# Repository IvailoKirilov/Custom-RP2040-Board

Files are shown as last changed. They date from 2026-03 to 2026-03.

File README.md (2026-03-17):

# Custom-RP2040-Board
This board is a simple RP2040 based MCU. The PCB was made with the help of the guide from Hack Club Stasis. 

I decided to make this board because I had wanted to make my own MCU for a while and when I saw the guide I instantly knew I had to make it. I learned quite a bit while making this project and now I will be bale to use this board for other projects.

This board has taken me about 7-8 hours to fully make. Below I have put some images of the finished board.

Schematic:

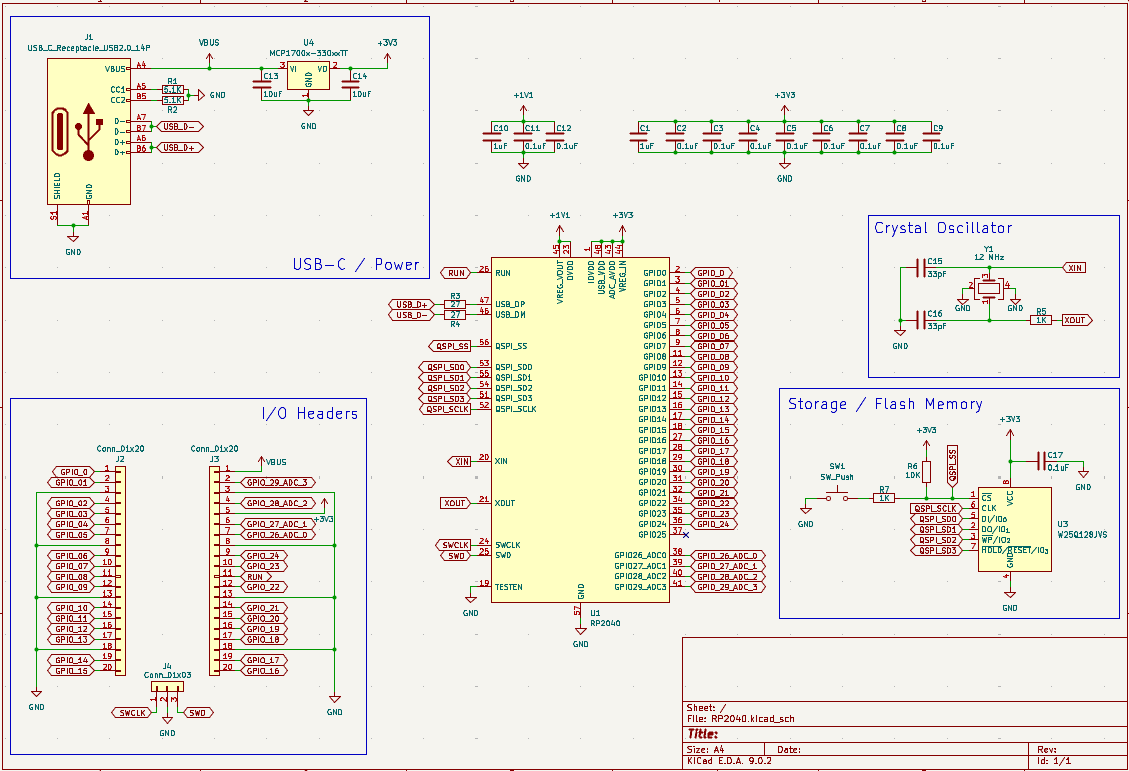
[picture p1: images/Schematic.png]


PCB (front):

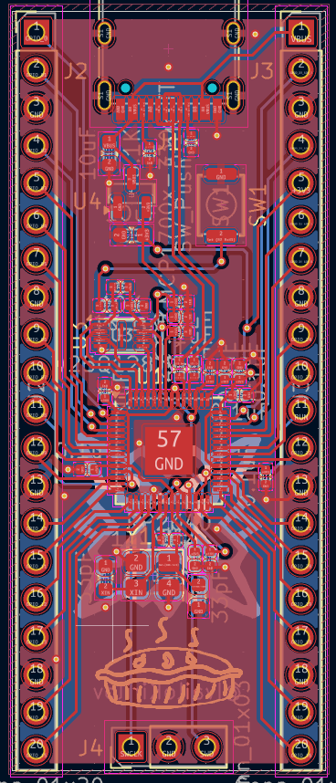
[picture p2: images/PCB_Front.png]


PCB (back):

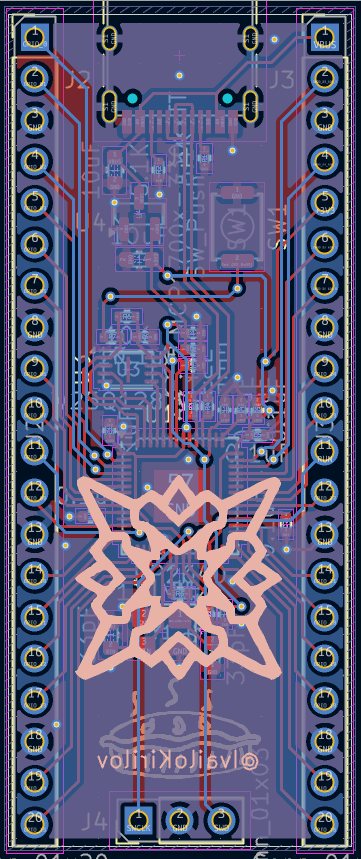
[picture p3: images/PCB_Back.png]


3D View (top):

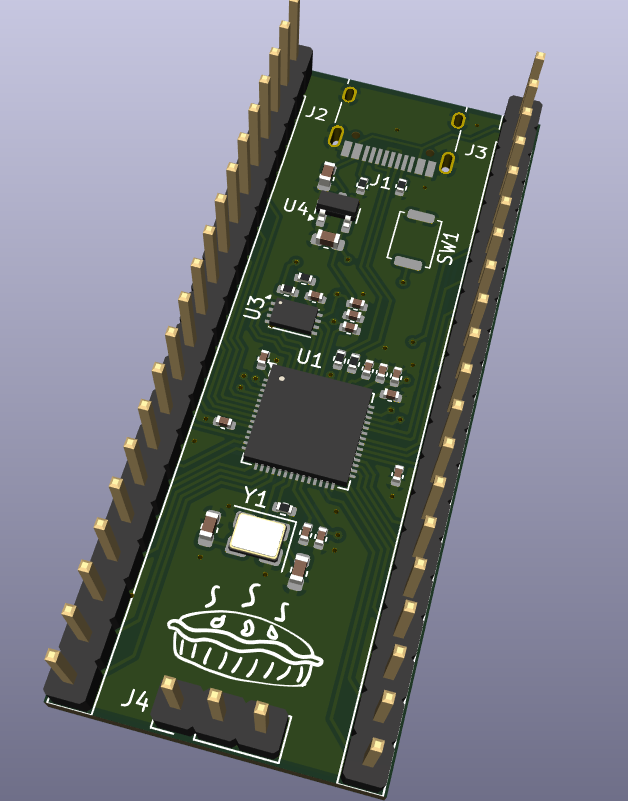
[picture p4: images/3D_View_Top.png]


3D View (bottom):

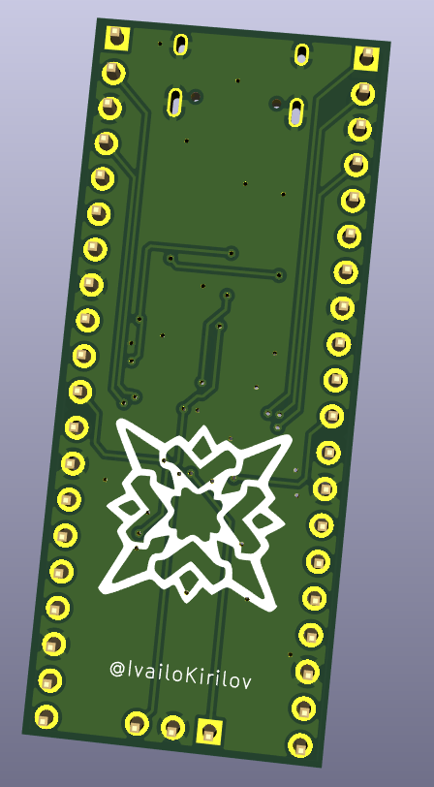
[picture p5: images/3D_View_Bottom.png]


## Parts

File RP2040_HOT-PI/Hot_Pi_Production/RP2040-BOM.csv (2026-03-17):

Id | Designator | Footprint | Quantity | Comment | Supplier and ref
1 | R5,R7 | R_0402_1005Metric | 2 | 1K
2 | SW1 | SW_Push_SPST_NO_Alps_SKRK | 1 | SW_Push
3 | C17,C9,C3,C2,C7,C6,C8,C11,C12,C4,C5 | C_0402_1005Metric | 11 | 0.1uF
4 | R3,R4 | R_0402_1005Metric | 2 | 27
5 | R6 | R_0402_1005Metric | 1 | 10K
6 | C16,C15 | C_0603_1608Metric | 2 | 33pF
7 | U3 | Winbond_USON-8-1EP_3x2mm_P0.5mm_EP0.2x1.6mm | 1 | W25Q128JVS
8 | C1,C10 | C_0402_1005Metric | 2 | 1uF
9 | R1,R2 | R_0402_1005Metric | 2 | 5.1K
10 | J2,J3 | PinHeader_1x20_P2.54mm_Vertical | 2 | Conn_01x20
11 | C13,C14 | C_0603_1608Metric | 2 | 10uF
12 | J4 | PinHeader_1x03_P2.54mm_Vertical | 1 | Conn_01x03
13 | Y1 | Crystal_SMD_3225-4Pin_3.2x2.5mm | 1 | 12 MHz
14 | U1 | QFN-56-1EP_7x7mm_P0.4mm_EP3.2x3.2mm | 1 | RP2040
15 | U4 | SOT-23 | 1 | MCP1700x-330xxTT
16 | J1 | USB_C_Receptacle_HRO_TYPE-C-31-M-12 | 1 | USB_C_Receptacle_USB2.0_14P

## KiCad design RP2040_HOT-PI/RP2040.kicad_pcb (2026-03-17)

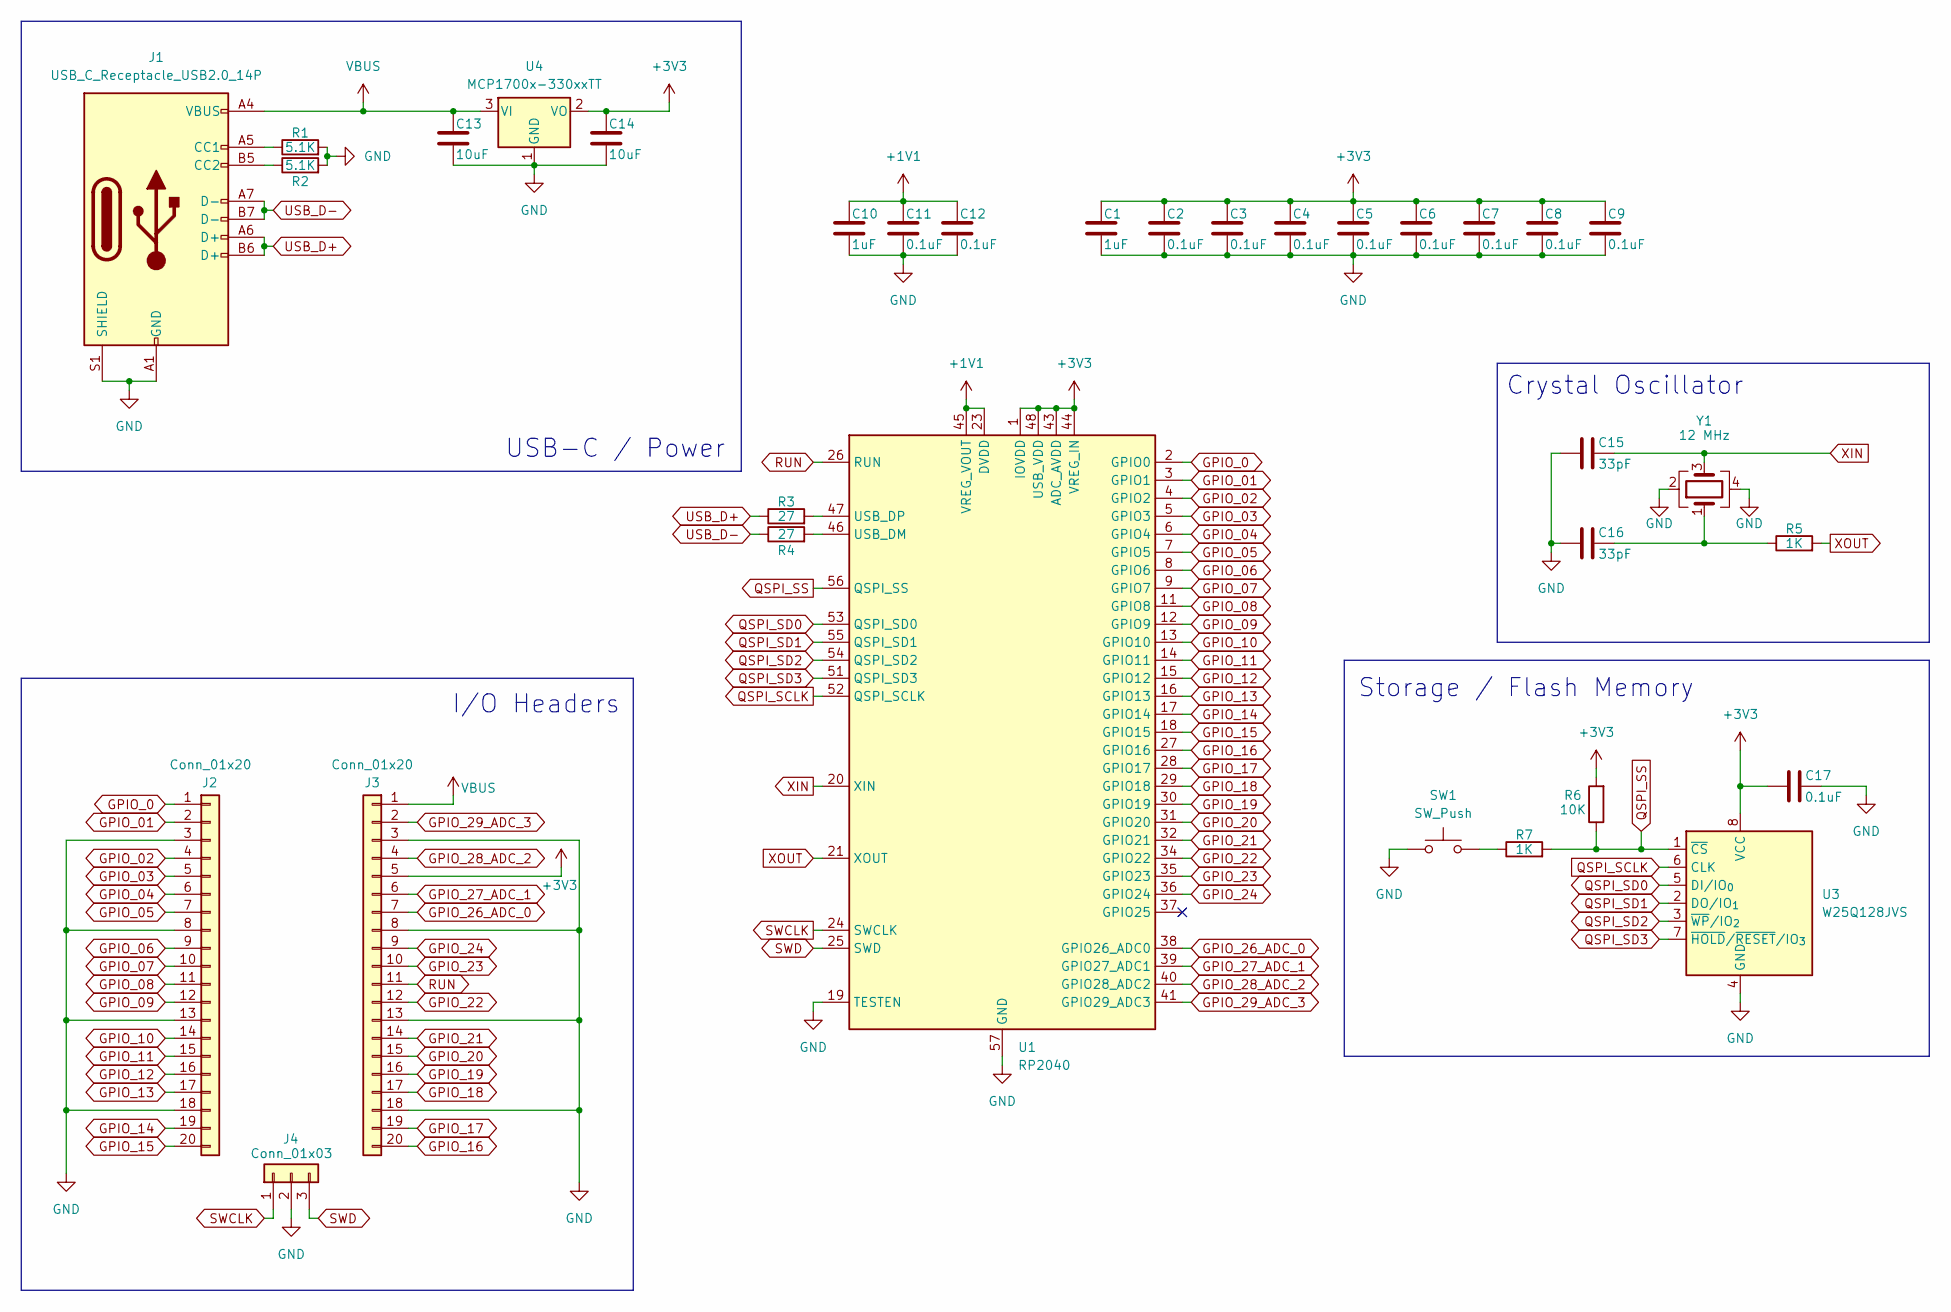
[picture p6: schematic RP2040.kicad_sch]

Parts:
C1, C10: 1uF; C_0402_1005Metric
C2, C3, C4, C5, C6, C7, C8, C9, C11, C12, C17: 0.1uF; C_0402_1005Metric
C13, C14: 10uF; C_0603_1608Metric
C15, C16: 33pF; C_0603_1608Metric
J1: USB_C_Receptacle_USB2.0_14P; USB_C_Receptacle_HRO_TYPE-C-31-M-12
J2, J3: Conn_01x20; PinHeader_1x20_P2.54mm_Vertical
J4: Conn_01x03; PinHeader_1x03_P2.54mm_Vertical
R1, R2: 5.1K; R_0402_1005Metric
R3, R4: 27; R_0402_1005Metric
R5, R7: 1K; R_0402_1005Metric
R6: 10K; R_0402_1005Metric
SW1: SW_Push; SW_Push_SPST_NO_Alps_SKRK
U1: RP2040; QFN-56-1EP_7x7mm_P0.4mm_EP3.2x3.2mm
U3: W25Q128JVS; Winbond_USON-8-1EP_3x2mm_P0.5mm_EP0.2x1.6mm
U4: MCP1700x-330xxTT; SOT-23
Y1: 12 MHz; Crystal_SMD_3225-4Pin_3.2x2.5mm

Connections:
+1V1: C10.1, C11.1, C12.1, U1.23 (DVDD), U1.45 (VREG_VOUT), U1.50 (DVDD)
+3V3: C1.1, C2.1, C3.1, C4.1, C5.1, C6.1, C7.1, C8.1, C9.1, C14.1, C17.1, J3.5, R6.2, U1.1 (IOVDD), U1.10 (IOVDD), U1.22 (IOVDD), U1.33 (IOVDD), U1.42 (IOVDD), U1.43 (ADC_AVDD), U1.44 (VREG_IN), U1.48 (USB_VDD), U1.49 (IOVDD), U3.8 (VCC), U4.2 (VO)
GND: C1.2, C2.2, C3.2, C4.2, C5.2, C6.2, C7.2, C8.2, C9.2, C10.2, C11.2, C12.2, C13.2, C14.2, C15.1, C16.1, C17.2, J1.A1 (GND), J1.A12 (GND), J1.B1 (GND), J1.B12 (GND), J1.S1 (SHIELD), J2.3, J2.8, J2.13, J2.18, J3.3, J3.8, J3.13, J3.18, J4.2, R1.2, R2.2, SW1.1, U1.19 (TESTEN), U1.57 (GND), U3.4 (GND), U4.1 (GND), Y1.2, Y1.4
GPIO_0: J2.1, U1.2 (GPIO0)
GPIO_01: J2.2, U1.3 (GPIO1)
GPIO_02: J2.4, U1.4 (GPIO2)
GPIO_03: J2.5, U1.5 (GPIO3)
GPIO_04: J2.6, U1.6 (GPIO4)
GPIO_05: J2.7, U1.7 (GPIO5)
GPIO_06: J2.9, U1.8 (GPIO6)
GPIO_07: J2.10, U1.9 (GPIO7)
GPIO_08: J2.11, U1.11 (GPIO8)
GPIO_09: J2.12, U1.12 (GPIO9)
GPIO_10: J2.14, U1.13 (GPIO10)
GPIO_11: J2.15, U1.14 (GPIO11)
GPIO_12: J2.16, U1.15 (GPIO12)
GPIO_13: J2.17, U1.16 (GPIO13)
GPIO_14: J2.19, U1.17 (GPIO14)
GPIO_15: J2.20, U1.18 (GPIO15)
GPIO_16: J3.20, U1.27 (GPIO16)
GPIO_17: J3.19, U1.28 (GPIO17)
GPIO_18: J3.17, U1.29 (GPIO18)
GPIO_19: J3.16, U1.30 (GPIO19)
GPIO_20: J3.15, U1.31 (GPIO20)
GPIO_21: J3.14, U1.32 (GPIO21)
GPIO_22: J3.12, U1.34 (GPIO22)
GPIO_23: J3.10, U1.35 (GPIO23)
GPIO_24: J3.9, U1.36 (GPIO24)
GPIO_26_ADC_0: J3.7, U1.38 (GPIO26_ADC0)
GPIO_27_ADC_1: J3.6, U1.39 (GPIO27_ADC1)
GPIO_28_ADC_2: J3.4, U1.40 (GPIO28_ADC2)
GPIO_29_ADC_3: J3.2, U1.41 (GPIO29_ADC3)
unnamed: C16.2, R5.1, Y1.1
unnamed: J1.A5 (CC1), R1.1
unnamed: J1.B5 (CC2), R2.1
unnamed: R7.1, SW1.2
unnamed: R4.2, U1.46 (USB_DM)
unnamed: R3.2, U1.47 (USB_DP)
QSPI_SCLK: U1.52 (QSPI_SCLK), U3.6 (CLK)
QSPI_SD0: U1.53 (QSPI_SD0), U3.5 (DI/IO_{0})
QSPI_SD1: U1.55 (QSPI_SD1), U3.2 (DO/IO_{1})
QSPI_SD2: U1.54 (QSPI_SD2), U3.3 (~WP/IO_{2})
QSPI_SD3: U1.51 (QSPI_SD3), U3.7 (~HOLD/~RESET/IO_{3})
QSPI_SS: R6.1, R7.2, U1.56 (QSPI_SS), U3.1 (~CS)
RUN: J3.11, U1.26 (RUN)
SWCLK: J4.1, U1.24 (SWCLK)
SWD: J4.3, U1.25 (SWD)
USB_D+: J1.A6 (D+), J1.B6 (D+), R3.1
USB_D-: J1.A7 (D-), J1.B7 (D-), R4.1
VBUS: C13.1, J1.A4 (VBUS), J1.A9 (VBUS), J1.B4 (VBUS), J1.B9 (VBUS), J3.1, U4.3 (VI)
XIN: C15.2, U1.20 (XIN), Y1.3
XOUT: R5.2, U1.21 (XOUT)

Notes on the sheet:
Storage / Flash Memory
I/O Headers
Crystal Oscillator
USB-C / Power

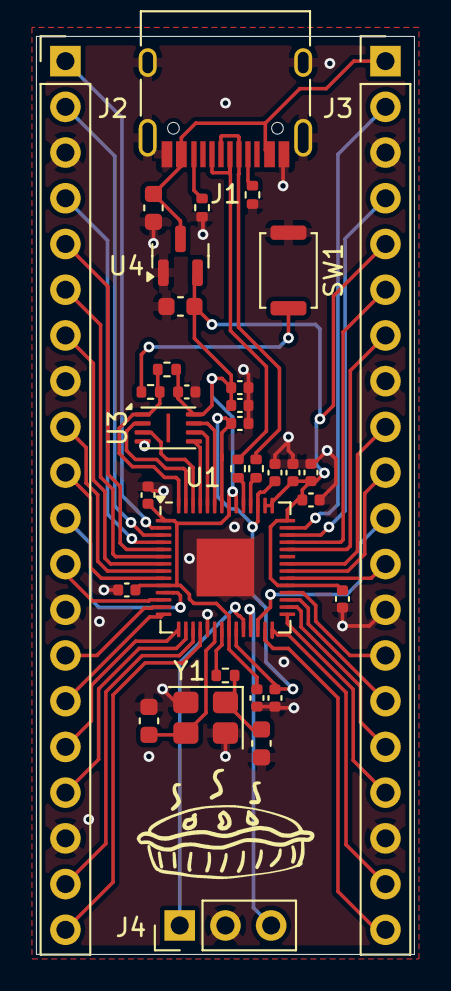
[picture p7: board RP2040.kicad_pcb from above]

Board: 2 copper layers, 21.0 x 51.0 mm, 33 parts (0 on the bottom side), 52 nets.

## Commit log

2026-03-12 Added the projects files
    Made the schematic.
    Started the PCB.
    [RP2040.kicad_pcb, RP2040.kicad_sch]
2026-03-14 Remade the traces on the PCB
    [RP2040.kicad_pcb, RP2040.kicad_sch]
2026-03-15 Added custom silkscreen
    [RP2040.kicad_pcb]
2026-03-17 Generated files for production
    [RP2040-BOM.csv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]
